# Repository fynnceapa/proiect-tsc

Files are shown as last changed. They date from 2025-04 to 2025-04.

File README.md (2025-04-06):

# OpenBook Project for Systems Testing
# Stan Andrei Razvan (Group 333CA)  

## Block Diagram
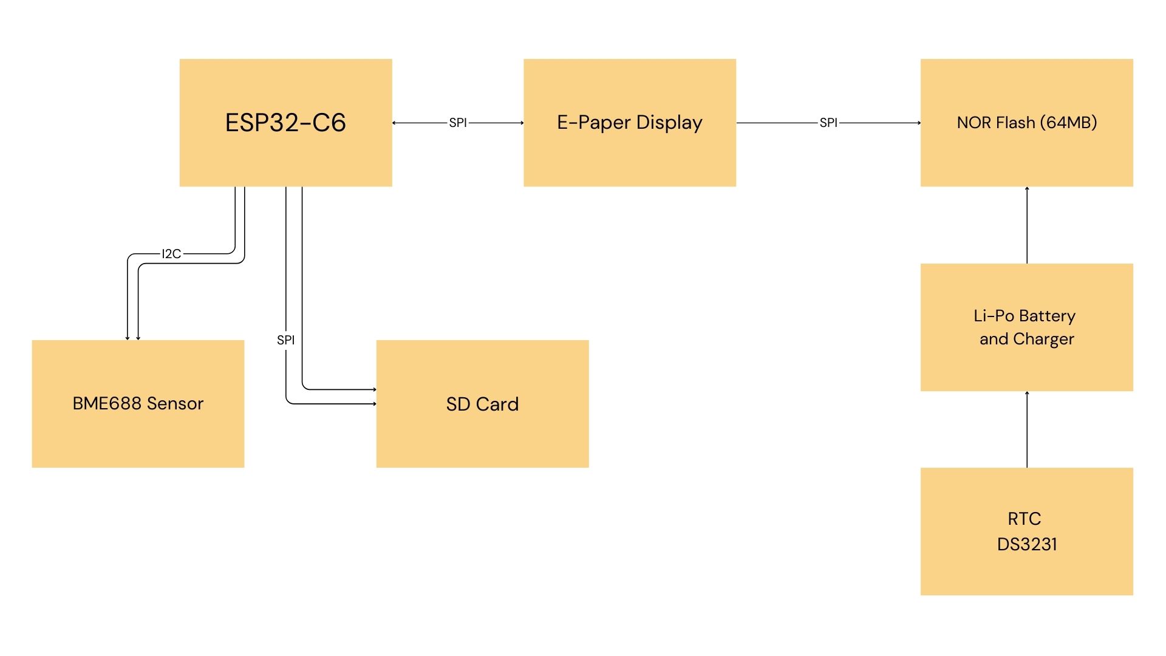
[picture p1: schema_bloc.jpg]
Block Diagram System Block Diagram
  

## Steps took
I followed the schematic and board layout provided by the teacher as closely as I could in Fusion 360.

The problems started when I began placing the components on the board. Most of the difficulties were related to identifying which discrete components to place and where, in order to make the routing process easier and more efficient.

I decided to route the board using two layers—top and bottom—and used vias where necessary. My lack of routing skills comes from the fact that i did not play around in Fusion that much...

## Core Components  

### 1. ESP32-C6 Microcontroller (Main Board)  
- **Processor:** 32-bit RISC-V @ 160MHz  
- **Wireless:** Wi-Fi 6 (802.11ax) + Bluetooth 5  
- **Memory:**  
  - 320KB RAM  
  - 512KB internal Flash (expandable via external NOR Flash)  
- **I/O:** 30+ GPIOs supporting SPI, I2C, UART, USB 2.0  

### 2. Peripheral Modules  

| Module | Interface | Speed | Key ESP32-C6 Pins |  
|---|---|---|---|
| E-Paper Display | SPI | 10-40 MHz | `EPD_CS`, MOSI, SCK |  
| BME688 Sensor | I2C | 400 kHz | SCL, SDA |  
| DS3231 RTC | I2C | 100 kHz | SCL, SDA |  
| NOR Flash | SPI/QSPI  | 133 MHz | `FLASH_CS`, MOSI, SCK |  
| SD Card | SPI | 25 MHz | `SS_SD`, MOSI, SCK |  

## Module Specifications  

### A. E-Paper Display  
- **Type:** SPI-based (e.g., Waveshare)  
- **Key Pins:**  
  - `EPD_RST`: Hardware reset  
  - `EPD_DC`: Data/command control  
  - `EPD_BUSY`: Status monitoring  
- **Power:**  
  - 150mA (active refresh)  
  - 0mA (static display)  

### B. BME688 Environmental Sensor  
- **Metrics:** Temperature, humidity, pressure, VOC  
- **Accuracy:** ±0.5°C, ±3% RH  
- **Power:** 3.6mA (active), 2.1µA (sleep)  

### C. DS3231 Real-Time Clock  
- **Precision:** ±2ppm (±1min/year)  
- **Features:** Battery backup (`VBAT`), alarm interrupts (`INT_RTC`)  

### D. Storage Systems  
- **NOR Flash (W25Q512JVEIQ):**  
  - 64MB capacity  
  - QSPI @ 133MHz  
- **SD Card:**  
  - SPI interface @ 25MHz  

### E. Power Management  
- **Charger:** MCP73831 (Li-Po, 5V USB → 4.2V)  
- **LDO Regulator:** XC6220A331MR-G (3.3V logic)  
- **Battery Monitor:** MAX17048G+T10 (I2C)  

## Power Analysis  
| Mode | Current Draw | Runtime* |  
|---|---|---|
| Active Operation | ~230mA | ~4h |  
| Deep Sleep | ~6µA | ~2 years |  

*With 1000mAh Li-Po battery  

## Low-Power Design Strategies  
- Deep-sleep mode with RTC wake-up  
- Selective peripheral power control  
- SPI/I2C bus deactivation when idle  

## Pinout Summary  

| Function | Key Pins | Purpose |  
|---|---|---|
| **E-Paper** | `EPD_CS`, `EPD_DC` | Display control |  
| **NOR Flash** | `FLASH_CS` | External memory access |  
| **RTC** | `INT_RTC`, `32KHZ` | Timekeeping & alarms |  
| **BME688** | `SCL`, `SDA` | Environmental sensing |  
| **Power** | `VBAT`, `3V3` | Battery & regulated power |

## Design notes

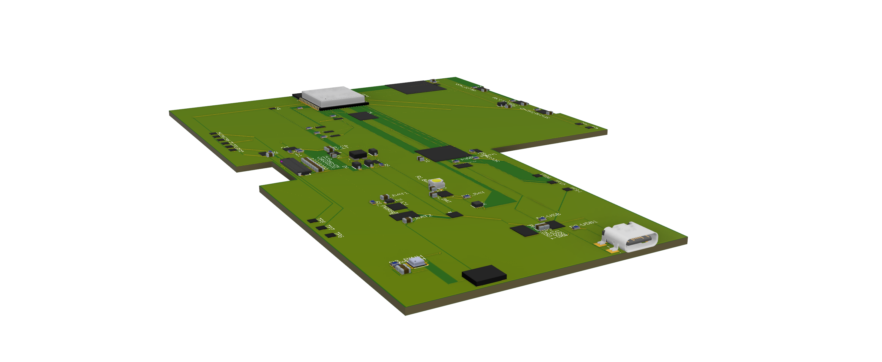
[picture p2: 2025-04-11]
Images/proiect2.png

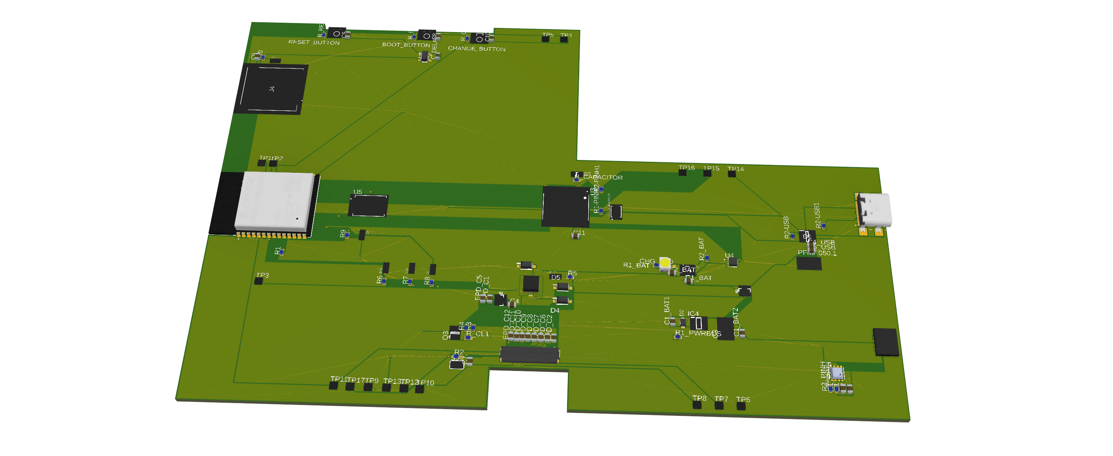
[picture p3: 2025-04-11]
Images/proiect.png

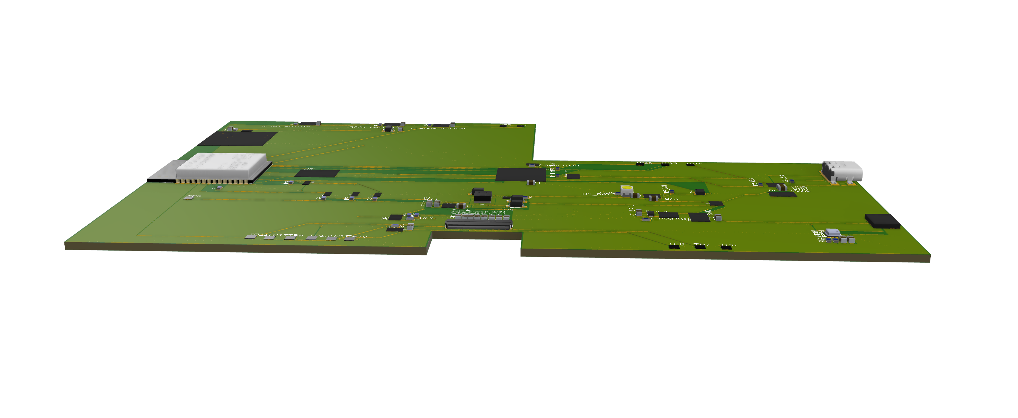
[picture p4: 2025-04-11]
Images/proiect3.png

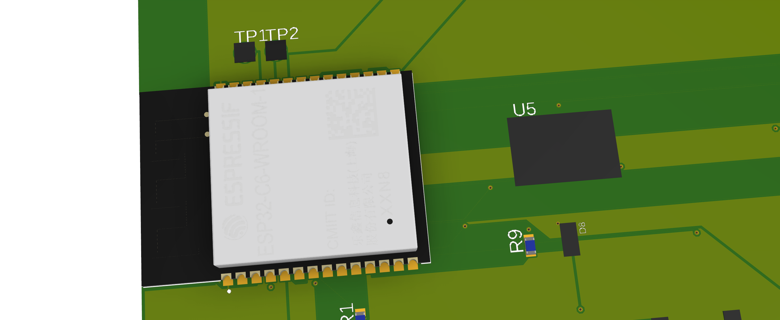
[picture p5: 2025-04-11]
Images/proiect4.png

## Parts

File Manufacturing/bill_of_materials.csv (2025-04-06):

Part | Value | Device | Package | Description | ARROW_PART_NUMBER | ARROW_PRICE-STOCK | AVAILABILITY | CENTROID_NOT_SPECIFIED | CHECK_PRICES | COPYRIGHT | DATASHEET | DESCRIPTION | DIGIKEY_DESCRIPTION | DIGIKEY_PART_NUMBER | HEIGHT | LEAD_FREE | MANUFACTURER_NAME | MANUFACTURER_PART_NUMBER | MF | MFR_NAME | MOUSER_PART_NUMBER | MOUSER_PRICE-STOCK | MOUSER_TESTING_PART_NUMBER | MOUSER_TESTING_PRICE-STOCK | MP | MPN | PACKAGE | POPULARITY | PREFIX | PRICE | PROD_ID | PURCHASE-URL | ROHS | SNAPEDA_LINK | SPICEMODEL | SPICEPREFIX | TEMPERATURE_RANGE_HIGH | TEMPERATURE_RANGE_LOW | TP_SIGNAL_NAME | VALUE
BOOT_BUTTON | BUTTON_CUSYOMV1 | BUTTON_CUSYOMV1 | MYBUTTON
C1 | 100nF | ESP32_WROVER_EAGLE-LTSPICE_CC0402 | ESP32_WROVER_EAGLE-LTSPICE_C0402 | CAPACITOR, European symbol |  |  |  |  |  |  |  |  |  |  |  |  |  |  |  |  |  |  |  |  |  |  |  |  |  |  |  |  |  |  | NONE | C
C1_BAT | 4.7uF | EAGLE-LTSPICE_CC0402 | EAGLE-LTSPICE_C0402 | CAPACITOR, European symbol |  |  |  |  |  |  |  |  |  |  |  |  |  |  |  |  |  |  |  |  |  |  |  |  |  |  |  |  |  |  | NONE | C
C1_BAT1 | 4.7uF | EAGLE-LTSPICE_CC0402 | EAGLE-LTSPICE_C0402 | CAPACITOR, European symbol |  |  |  |  |  |  |  |  |  |  |  |  |  |  |  |  |  |  |  |  |  |  |  |  |  |  |  |  |  |  | NONE | C
C1_BAT2 | 4.7uF | EAGLE-LTSPICE_CC0402 | EAGLE-LTSPICE_C0402 | CAPACITOR, European symbol |  |  |  |  |  |  |  |  |  |  |  |  |  |  |  |  |  |  |  |  |  |  |  |  |  |  |  |  |  |  | NONE | C
C2 | 100nF | ESP32_WROVER_EAGLE-LTSPICE_CC0402 | ESP32_WROVER_EAGLE-LTSPICE_C0402 | CAPACITOR, European symbol |  |  |  |  |  |  |  |  |  |  |  |  |  |  |  |  |  |  |  |  |  |  |  |  |  |  |  |  |  |  | NONE | C
C2_BAT | 4.7uF | EAGLE-LTSPICE_CC0402 | EAGLE-LTSPICE_C0402 | CAPACITOR, European symbol |  |  |  |  |  |  |  |  |  |  |  |  |  |  |  |  |  |  |  |  |  |  |  |  |  |  |  |  |  |  | NONE | C
C3 | 100uF TANT | RCL_CPOL-EUCT3528 | RCL_CT3528 | POLARIZED CAPACITOR, European symbol |  |  |  |  |  |  |  |  |  |  |  |  |  |  |  |  |  |  |  |  |  |  |  | 0 |  |  |  |  |  |  |  | C
C4 | 4.7uF/25V | EAGLE-LTSPICE_CC0402 | EAGLE-LTSPICE_C0402 | CAPACITOR, European symbol |  |  |  |  |  |  |  |  |  |  |  |  |  |  |  |  |  |  |  |  |  |  |  |  |  |  |  |  |  |  | NONE | C
C4_USB | 100nF | EAGLE-LTSPICE_CC0402 | EAGLE-LTSPICE_C0402 | CAPACITOR, European symbol |  |  |  |  |  |  |  |  |  |  |  |  |  |  |  |  |  |  |  |  |  |  |  |  |  |  |  |  |  |  | NONE | C
C5 | 1uF | EAGLE-LTSPICE_CC0402 | EAGLE-LTSPICE_C0402 | CAPACITOR, European symbol |  |  |  |  |  |  |  |  |  |  |  |  |  |  |  |  |  |  |  |  |  |  |  |  |  |  |  |  |  |  | NONE | C
C5_USB | 4.7uF | EAGLE-LTSPICE_CC0402 | EAGLE-LTSPICE_C0402 | CAPACITOR, European symbol |  |  |  |  |  |  |  |  |  |  |  |  |  |  |  |  |  |  |  |  |  |  |  |  |  |  |  |  |  |  | NONE | C
C7 | 10uF | EAGLE-LTSPICE_CC0402 | EAGLE-LTSPICE_C0402 | CAPACITOR, European symbol |  |  |  |  |  |  |  |  |  |  |  |  |  |  |  |  |  |  |  |  |  |  |  |  |  |  |  |  |  |  | NONE | C
C8 | 100nF | EAGLE-LTSPICE_CC0402 | EAGLE-LTSPICE_C0402 | CAPACITOR, European symbol |  |  |  |  |  |  |  |  |  |  |  |  |  |  |  |  |  |  |  |  |  |  |  |  |  |  |  |  |  |  | NONE | C
C9 |  | EAGLE-LTSPICE_CC0402 | EAGLE-LTSPICE_C0402 | CAPACITOR, European symbol |  |  |  |  |  |  |  |  |  |  |  |  |  |  |  |  |  |  |  |  |  |  |  |  |  |  |  |  |  |  | NONE | C
C10 | 100nF | EAGLE-LTSPICE_CC0402 | EAGLE-LTSPICE_C0402 | CAPACITOR, European symbol |  |  |  |  |  |  |  |  |  |  |  |  |  |  |  |  |  |  |  |  |  |  |  |  |  |  |  |  |  |  | NONE | C
C10_SUPERCAP | CPH3225A | CPH3225A | CAPCP3225X100N | Cap 0.011F 3.3V 1210 Flat Check availability |  |  | Not in stock |  | https://www.snapeda.com/parts/CPH3225A/Seiko+Instruments/view-part/?ref=eda |  |  | 11 mF (EDLC) Supercapacitor 3.3 V 1210 (3225 Metric) - - |  |  |  |  |  |  | Seiko Instruments |  |  |  |  |  | CPH3225A |  | 1210 Seiko |  |  | None |  | https://www.snapeda.com/api/url_track_click_mouser/?unipart_id=562593&manufacturer=Seiko Instruments&part_name=CPH3225A&search_term=None |  | https://www.snapeda.com/parts/CPH3225A/Seiko+Instruments/view-part/?ref=snap
C11 | 100nF | EAGLE-LTSPICE_CC0402 | EAGLE-LTSPICE_C0402 | CAPACITOR, European symbol |  |  |  |  |  |  |  |  |  |  |  |  |  |  |  |  |  |  |  |  |  |  |  |  |  |  |  |  |  |  | NONE | C
CHANGE_BUTTON | BUTTON_CUSYOMV1 | BUTTON_CUSYOMV1 | MYBUTTON
CHG_LED |  | ADAFRUIT_LEDCHIP-LED0603 | ADAFRUIT_CHIP-LED0603 | LED
C_DELAY | 100nF | EAGLE-LTSPICE_CC0402 | EAGLE-LTSPICE_C0402 | CAPACITOR, European symbol |  |  |  |  |  |  |  |  |  |  |  |  |  |  |  |  |  |  |  |  |  |  |  |  |  |  |  |  |  |  | NONE | C
D1 | USBLC6-2SC6Y | USBLC6-2SC6Y | SOT95P280X145-6N | Low Cap. ESD Protection Auto SOT-23-6 STMicroelectronics USBLC6-2SC6Y, Dual Uni-Directional TVS Diode Array, 6-Pin SOT-23 |  |  | In Stock |  | https://www.snapeda.com/parts/USBLC6-2SC6Y/STMicroelectronics/view-part/?ref=eda |  |  | 17V Clamp 5A (8/20µs) Ipp Tvs Diode Surface Mount SOT-23-6 |  |  |  |  |  |  | STMicroelectronics |  |  |  |  |  | USBLC6-2SC6Y |  | SOT-23-6 STMicroelectronics |  |  | None |  |  |  | https://www.snapeda.com/parts/USBLC6-2SC6Y/STMicroelectronics/view-part/?ref=snap
D2 | ESP32_WROVER_AVX---SD0805S020S1R0_AVX_SD0805S020S1R0_0_0AVX_SD0805S020S1R0_0_0 | ESP32_WROVER_AVX---SD0805S020S1R0_AVX_SD0805S020S1R0_0_0AVX_SD0805S020S1R0_0_0 | ESP32_WROVER_AVX---SD0805S020S1R0_AVX_SD0805S020S1R0_0 | Schottky Barrier Rectifier Diode |  |  |  | No |  |  | http://datasheets.avx.com/schottky.pdf |  | DIODE SCHOTTKY 20V 1A 0805 | 478-7800-1-ND |  | yes |  |  | AVX |  | 581-SD0805S020S1R0 |  |  |  |  |  | 0805 (2012 metric) |  | D |  |  |  | yes |  |  |  | +125°C | -55°C
D3 | MBR0530 | MBR0530 | SOD3716X135N | ON SEMICONDUCTOR - MBR0530 - DIODE, SCHOTTKY, 0.5A, 30V, SOD-123 |  |  | In Stock |  | https://www.snapeda.com/parts/MBR0530/Onsemi/view-part/?ref=eda |  |  | Diode Schottky 30 V 500mA Surface Mount SOD-123 |  |  |  |  |  |  | ON Semiconductor |  |  |  |  |  | MBR0530 |  | SOD-123-2 ON Semiconductor |  |  | None |  | https://www.snapeda.com/api/url_track_click_mouser/?unipart_id=179458&manufacturer=ON Semiconductor&part_name=MBR0530&search_term=None |  | https://www.snapeda.com/parts/MBR0530/Onsemi/view-part/?ref=snap
D4 | MBR0530 | MBR0530 | SOD3716X135N | ON SEMICONDUCTOR - MBR0530 - DIODE, SCHOTTKY, 0.5A, 30V, SOD-123 |  |  | In Stock |  | https://www.snapeda.com/parts/MBR0530/Onsemi/view-part/?ref=eda |  |  | Diode Schottky 30 V 500mA Surface Mount SOD-123 |  |  |  |  |  |  | ON Semiconductor |  |  |  |  |  | MBR0530 |  | SOD-123-2 ON Semiconductor |  |  | None |  | https://www.snapeda.com/api/url_track_click_mouser/?unipart_id=179458&manufacturer=ON Semiconductor&part_name=MBR0530&search_term=None |  | https://www.snapeda.com/parts/MBR0530/Onsemi/view-part/?ref=snap
D5 | MBR0530 | MBR0530 | SOD3716X135N | ON SEMICONDUCTOR - MBR0530 - DIODE, SCHOTTKY, 0.5A, 30V, SOD-123 |  |  | In Stock |  | https://www.snapeda.com/parts/MBR0530/Onsemi/view-part/?ref=eda |  |  | Diode Schottky 30 V 500mA Surface Mount SOD-123 |  |  |  |  |  |  | ON Semiconductor |  |  |  |  |  | MBR0530 |  | SOD-123-2 ON Semiconductor |  |  | None |  | https://www.snapeda.com/api/url_track_click_mouser/?unipart_id=179458&manufacturer=ON Semiconductor&part_name=MBR0530&search_term=None |  | https://www.snapeda.com/parts/MBR0530/Onsemi/view-part/?ref=snap
D6 | PGB1010603MR | PGB1010603MR | DIOC1608X36N | Check availability |  |  | In Stock |  | https://www.snapeda.com/parts/PGB1010603MR/Littelfuse/view-part/?ref=eda |  |  | 150V (Typ) Clamp - Ipp Tvs Diode Surface Mount 0603 (1608 Metric) |  |  |  |  |  |  | Littelfuse Inc. |  |  |  |  |  | PGB1010603MR |  | 0603 Littelfuse Inc. |  |  | None |  | https://www.snapeda.com/api/url_track_click_mouser/?unipart_id=5659453&manufacturer=Littelfuse Inc.&part_name=PGB1010603MR&search_term=None |  | https://www.snapeda.com/parts/PGB1010603MR/Littelfuse/view-part/?ref=snap
D7 | ESP32_WROVER_AVX---SD0805S020S1R0_AVX_SD0805S020S1R0_0_0AVX_SD0805S020S1R0_0_0 | ESP32_WROVER_AVX---SD0805S020S1R0_AVX_SD0805S020S1R0_0_0AVX_SD0805S020S1R0_0_0 | ESP32_WROVER_AVX---SD0805S020S1R0_AVX_SD0805S020S1R0_0 | Schottky Barrier Rectifier Diode |  |  |  | No |  |  | http://datasheets.avx.com/schottky.pdf |  | DIODE SCHOTTKY 20V 1A 0805 | 478-7800-1-ND |  | yes |  |  | AVX |  | 581-SD0805S020S1R0 |  |  |  |  |  | 0805 (2012 metric) |  | D |  |  |  | yes |  |  |  | +125°C | -55°C
D8 | PGB1010603MR | PGB1010603MR | DIOC1608X36N | Check availability |  |  | In Stock |  | https://www.snapeda.com/parts/PGB1010603MR/Littelfuse/view-part/?ref=eda |  |  | 150V (Typ) Clamp - Ipp Tvs Diode Surface Mount 0603 (1608 Metric) |  |  |  |  |  |  | Littelfuse Inc. |  |  |  |  |  | PGB1010603MR |  | 0603 Littelfuse Inc. |  |  | None |  | https://www.snapeda.com/api/url_track_click_mouser/?unipart_id=5659453&manufacturer=Littelfuse Inc.&part_name=PGB1010603MR&search_term=None |  | https://www.snapeda.com/parts/PGB1010603MR/Littelfuse/view-part/?ref=snap
D9 | PGB1010603MR | PGB1010603MR | DIOC1608X36N | Check availability |  |  | In Stock |  | https://www.snapeda.com/parts/PGB1010603MR/Littelfuse/view-part/?ref=eda |  |  | 150V (Typ) Clamp - Ipp Tvs Diode Surface Mount 0603 (1608 Metric) |  |  |  |  |  |  | Littelfuse Inc. |  |  |  |  |  | PGB1010603MR |  | 0603 Littelfuse Inc. |  |  | None |  | https://www.snapeda.com/api/url_track_click_mouser/?unipart_id=5659453&manufacturer=Littelfuse Inc.&part_name=PGB1010603MR&search_term=None |  | https://www.snapeda.com/parts/PGB1010603MR/Littelfuse/view-part/?ref=snap
D10 | PGB1010603MR | PGB1010603MR | DIOC1608X36N | Check availability |  |  | In Stock |  | https://www.snapeda.com/parts/PGB1010603MR/Littelfuse/view-part/?ref=eda |  |  | 150V (Typ) Clamp - Ipp Tvs Diode Surface Mount 0603 (1608 Metric) |  |  |  |  |  |  | Littelfuse Inc. |  |  |  |  |  | PGB1010603MR |  | 0603 Littelfuse Inc. |  |  | None |  | https://www.snapeda.com/api/url_track_click_mouser/?unipart_id=5659453&manufacturer=Littelfuse Inc.&part_name=PGB1010603MR&search_term=None |  | https://www.snapeda.com/parts/PGB1010603MR/Littelfuse/view-part/?ref=snap
D11 | PGB1010603MR | PGB1010603MR | DIOC1608X36N | Check availability |  |  | In Stock |  | https://www.snapeda.com/parts/PGB1010603MR/Littelfuse/view-part/?ref=eda |  |  | 150V (Typ) Clamp - Ipp Tvs Diode Surface Mount 0603 (1608 Metric) |  |  |  |  |  |  | Littelfuse Inc. |  |  |  |  |  | PGB1010603MR |  | 0603 Littelfuse Inc. |  |  | None |  | https://www.snapeda.com/api/url_track_click_mouser/?unipart_id=5659453&manufacturer=Littelfuse Inc.&part_name=PGB1010603MR&search_term=None |  | https://www.snapeda.com/parts/PGB1010603MR/Littelfuse/view-part/?ref=snap
D12 | PGB1010603MR | PGB1010603MR | DIOC1608X36N | Check availability |  |  | In Stock |  | https://www.snapeda.com/parts/PGB1010603MR/Littelfuse/view-part/?ref=eda |  |  | 150V (Typ) Clamp - Ipp Tvs Diode Surface Mount 0603 (1608 Metric) |  |  |  |  |  |  | Littelfuse Inc. |  |  |  |  |  | PGB1010603MR |  | 0603 Littelfuse Inc. |  |  | None |  | https://www.snapeda.com/api/url_track_click_mouser/?unipart_id=5659453&manufacturer=Littelfuse Inc.&part_name=PGB1010603MR&search_term=None |  | https://www.snapeda.com/parts/PGB1010603MR/Littelfuse/view-part/?ref=snap
EPD_C1 | 1uF/50V | EAGLE-LTSPICE_CC0402 | EAGLE-LTSPICE_C0402 | CAPACITOR, European symbol |  |  |  |  |  |  |  |  |  |  |  |  |  |  |  |  |  |  |  |  |  |  |  |  |  |  |  |  |  |  | NONE | C
EPD_C2 | 1uF/50V | EAGLE-LTSPICE_CC0402 | EAGLE-LTSPICE_C0402 | CAPACITOR, European symbol |  |  |  |  |  |  |  |  |  |  |  |  |  |  |  |  |  |  |  |  |  |  |  |  |  |  |  |  |  |  | NONE | C
EPD_C5 | 0.1uF/50V | EAGLE-LTSPICE_CC0402 | EAGLE-LTSPICE_C0402 | CAPACITOR, European symbol |  |  |  |  |  |  |  |  |  |  |  |  |  |  |  |  |  |  |  |  |  |  |  |  |  |  |  |  |  |  | NONE | C
EPD_C6 | 1uF/50V | EAGLE-LTSPICE_CC0402 | EAGLE-LTSPICE_C0402 | CAPACITOR, European symbol |  |  |  |  |  |  |  |  |  |  |  |  |  |  |  |  |  |  |  |  |  |  |  |  |  |  |  |  |  |  | NONE | C
EPD_C7 | 1uF/50V | EAGLE-LTSPICE_CC0402 | EAGLE-LTSPICE_C0402 | CAPACITOR, European symbol |  |  |  |  |  |  |  |  |  |  |  |  |  |  |  |  |  |  |  |  |  |  |  |  |  |  |  |  |  |  | NONE | C
EPD_C8 | 1uF/50V | EAGLE-LTSPICE_CC0402 | EAGLE-LTSPICE_C0402 | CAPACITOR, European symbol |  |  |  |  |  |  |  |  |  |  |  |  |  |  |  |  |  |  |  |  |  |  |  |  |  |  |  |  |  |  | NONE | C
EPD_C9 | 1uF/50V | EAGLE-LTSPICE_CC0402 | EAGLE-LTSPICE_C0402 | CAPACITOR, European symbol |  |  |  |  |  |  |  |  |  |  |  |  |  |  |  |  |  |  |  |  |  |  |  |  |  |  |  |  |  |  | NONE | C
EPD_C10 | 1uF/50V | EAGLE-LTSPICE_CC0402 | EAGLE-LTSPICE_C0402 | CAPACITOR, European symbol |  |  |  |  |  |  |  |  |  |  |  |  |  |  |  |  |  |  |  |  |  |  |  |  |  |  |  |  |  |  | NONE | C
EPD_C11 | 1uF/50V | EAGLE-LTSPICE_CC0402 | EAGLE-LTSPICE_C0402 | CAPACITOR, European symbol |  |  |  |  |  |  |  |  |  |  |  |  |  |  |  |  |  |  |  |  |  |  |  |  |  |  |  |  |  |  | NONE | C
EPD_C12 | 1uF/50V | EAGLE-LTSPICE_CC0402 | EAGLE-LTSPICE_C0402 | CAPACITOR, European symbol |  |  |  |  |  |  |  |  |  |  |  |  |  |  |  |  |  |  |  |  |  |  |  |  |  |  |  |  |  |  | NONE | C
IC1 | BD5229G-TR | BD5229G-TR | SOT95P280X125-5N | Voltage Detector with Adjustable Delay Time: CMOS processes are utilized to develop high precision, low current consumption CMOS reset ICs that allow arbitrary setting of the delay time. The extensive lineup includes both Nch Open Drain and CMOS output types in a wide range of detection voltages (from 2.3V to 6.0V, in 0.1V steps), enabling selection of the ideal solution based on customer requirements. In addition, the entire series is of course both lead-free and RoHS-compliant. |  |  |  |  |  |  |  | Voltage Detector with Adjustable Delay Time: CMOS processes are utilized to develop high precision | low current consumption CMOS reset ICs that allow arbitrary setting of the delay time. The extensive lineup includes both Nch Open Drain and CMOS output types in a wide range of detection voltages (from 2.3V to 6.0V | in 0.1V steps) | enabling selection of the ideal solution based on customer requirements. In addition | the entire series is of course both lead-free and RoHS-compliant. |  |  | 1.25mm |  | ROHM Semiconductor | BD5229G-TR |  |  | 755-BD5229G-TR | https://www.mouser.co.uk/ProductDetail/ROHM-Semiconductor/BD5229G-TR?qs=4kLU8WoGk0vvnhrrYwdszw%3D%3D
IC4 | XC6220A331MR-G | XC6220A331MR-G | SOT95P280X120-5N | LDO Voltage Regulators |  |  |  |  |  |  |  | LDO Voltage Regulators |  |  | 1.2mm |  | Torex | XC6220A331MR-G |  |  | 865-XC6220A331MR-G | https://www.mouser.co.uk/ProductDetail/Torex-Semiconductor/XC6220A331MR-G?qs=AsjdqWjXhJ8ZSWznL1J0gg%3D%3D
J1 | FH34SRJ-24S-0.5SH_99_ | FH34SRJ-24S-0.5SH_99_ | FH34SRJ24S05SH99 | (0.50mm) Surface Mount, Right Angle |  |  |  |  |  |  |  | 24 Position FFC | FPC Connector Contacts | (0.50mm) Surface Mount | Right Angle |  |  | 1.1mm |  | Hirose | FH34SRJ-24S-0.5SH(99) |  |  | 798-FH34SRJ24S05SH99 | https://www.mouser.co.uk/ProductDetail/Hirose-Connector/FH34SRJ-24S-0.5SH99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
J2 | SAMACSYS_PARTS_USB4110-GF-A | SAMACSYS_PARTS_USB4110-GF-A | SAMACSYS_PARTS_USB4110GFA | CONN USB 2.0 TYPE-C R/A SMT |  |  |  |  |  |  |  | CONN USB 2.0 TYPE-C R/A SMT |  |  | 3.26mm |  | GCT (GLOBAL CONNECTOR TECHNOLOGY) | USB4110-GF-A |  |  | 640-USB4110-GF-A | https://www.mouser.co.uk/ProductDetail/GCT/USB4110-GF-A?qs=KUoIvG%2F9IlYiZvIXQjyJeA%3D%3D
J3 | QWIIC_RIGHT_ANGLE | QWIIC_CONNECTORJS-1MM | JST04_1MM_RA | SparkFun I2C Standard Qwiic Connector |  |  |  |  |  |  |  |  |  |  |  |  |  |  |  |  |  |  |  |  |  |  |  |  |  |  | CONN-13694 |  |  |  |  |  |  |  |  | QWIIC_RIGHT_ANGLE
J4 | 112A-TAAR-R03_ATTEND | 112A-TAAR-R03_ATTEND | 112ATAARR03ATTEND | Micro SD Card Socket, Push-Push Type, Top Mount, SMT, H=1.83mm, 10u |  |  |  |  |  |  |  | Micro SD Card Socket | Push-Push Type | Top Mount | SMT | H=1.83mm | 10u |  |  | 1.9mm |  | ATTEND | 112A-TAAR-R03 ATTEND
L1 | 68uH | 744043680IND_4828-WE-TPC_WRE | IND_4828-WE-TPC_WRE |  |  |  |  |  |  | Copyright (C) 2024 Ultra Librarian. All rights reserved. |  |  |  |  |  |  |  | 744043680 |  | Wurth Electronics
PFMF.050.1 | ESP32C6_VARISTORCN1812 | ESP32C6_VARISTORCN1812 | ESP32C6_VARISTOR_CT/CN1812 | VARISTOR |  |  |  |  |  |  |  |  |  |  |  |  |  |  |  |  |  |  |  |  |  |  |  | 0
Q1 | 20V/4.2A/52mΩ/1.4W | ESP32_WROVER_SPARKFUN-DISCRETESEMI_MOSFET_PCH-DMG2305UX-7 | ESP32_WROVER_SPARKFUN-DISCRETESEMI_SOT23-3 | P-channel MOSFETs |  |  |  |  |  |  |  |  |  |  |  |  |  |  |  |  |  |  |  |  |  |  |  |  |  |  | TRAN-14388 |  |  |  |  |  |  |  |  | 20V/4.2A/52mΩ/1.4W
Q2 | 20V/4.2A/52mΩ/1.4W | ESP32_WROVER_SPARKFUN-DISCRETESEMI_MOSFET_PCH-DMG2305UX-7 | ESP32_WROVER_SPARKFUN-DISCRETESEMI_SOT23-3 | P-channel MOSFETs |  |  |  |  |  |  |  |  |  |  |  |  |  |  |  |  |  |  |  |  |  |  |  |  |  |  | TRAN-14388 |  |  |  |  |  |  |  |  | 20V/4.2A/52mΩ/1.4W
Q3 | SI1308EDL-T1-GE3 | SI1308EDL-T1-GE3 | SOT65P210X110-3N | MOSFET N-Ch 30V 1.5A TrenchFET SC70 Vishay Si1308EDL-T1-GE3 N-channel MOSFET Transistor, 1.5 A, 30 V, 3-Pin SC-70 |  |  | In Stock |  | https://www.snapeda.com/parts/SI1308EDL-T1-GE3/Vishay+Siliconix/view-part/?ref=eda |  |  | Si1308EDL-T1-GE3 N-channel MOSFET Transistor | 1.5 A | 30 V | 3-Pin SC-70 | Siliconix / Vishay SI1308EDL-T1-GE3 |  |  |  |  |  |  | Vishay Siliconix |  |  |  |  |  | SI1308EDL-T1-GE3 |  | SOT-323 Vishay Semiconductor |  |  | None |  | https://www.snapeda.com/api/url_track_click_mouser/?unipart_id=274603&manufacturer=Vishay Siliconix&part_name=SI1308EDL-T1-GE3&search_term=None |  | https://www.snapeda.com/parts/SI1308EDL-T1-GE3/Vishay+Siliconix/view-part/?ref=snap
R1 | 10K | ESP32_WROVER_EAGLE-LTSPICE_RR0402 | ESP32_WROVER_EAGLE-LTSPICE_R0402 | RESISTOR, European symbol |  |  |  |  |  |  |  |  |  |  |  |  |  |  |  |  |  |  |  |  |  |  |  |  |  |  |  |  |  |  | NONE | R
R1-PINH1 | 10k | ESP32_WROVER_EAGLE-LTSPICE_RR0402 | ESP32_WROVER_EAGLE-LTSPICE_R0402 | RESISTOR, European symbol |  |  |  |  |  |  |  |  |  |  |  |  |  |  |  |  |  |  |  |  |  |  |  |  |  |  |  |  |  |  | NONE | R
R1_BAT | 200 | ESP32_WROVER_EAGLE-LTSPICE_RR0402 | ESP32_WROVER_EAGLE-LTSPICE_R0402 | RESISTOR, European symbol |  |  |  |  |  |  |  |  |  |  |  |  |  |  |  |  |  |  |  |  |  |  |  |  |  |  |  |  |  |  | NONE | R
R1_PINH |  | ESP32_WROVER_EAGLE-LTSPICE_RR0402 | ESP32_WROVER_EAGLE-LTSPICE_R0402 | RESISTOR, European symbol |  |  |  |  |  |  |  |  |  |  |  |  |  |  |  |  |  |  |  |  |  |  |  |  |  |  |  |  |  |  | NONE | R
R1_PWRBUS | 100k | ESP32_WROVER_EAGLE-LTSPICE_RR0402 | ESP32_WROVER_EAGLE-LTSPICE_R0402 | RESISTOR, European symbol |  |  |  |  |  |  |  |  |  |  |  |  |  |  |  |  |  |  |  |  |  |  |  |  |  |  |  |  |  |  | NONE | R
R2 | 2.2 | ESP32_WROVER_EAGLE-LTSPICE_RR0402 | ESP32_WROVER_EAGLE-LTSPICE_R0402 | RESISTOR, European symbol |  |  |  |  |  |  |  |  |  |  |  |  |  |  |  |  |  |  |  |  |  |  |  |  |  |  |  |  |  |  | NONE | R
R2-PINH1 | 10k | ESP32_WROVER_EAGLE-LTSPICE_RR0402 | ESP32_WROVER_EAGLE-LTSPICE_R0402 | RESISTOR, European symbol |  |  |  |  |  |  |  |  |  |  |  |  |  |  |  |  |  |  |  |  |  |  |  |  |  |  |  |  |  |  | NONE | R
R2-USB | 5k1 | ESP32_WROVER_EAGLE-LTSPICE_RR0402 | ESP32_WROVER_EAGLE-LTSPICE_R0402 | RESISTOR, European symbol |  |  |  |  |  |  |  |  |  |  |  |  |  |  |  |  |  |  |  |  |  |  |  |  |  |  |  |  |  |  | NONE | R
R2-USB1 | 5k1 | ESP32_WROVER_EAGLE-LTSPICE_RR0402 | ESP32_WROVER_EAGLE-LTSPICE_R0402 | RESISTOR, European symbol |  |  |  |  |  |  |  |  |  |  |  |  |  |  |  |  |  |  |  |  |  |  |  |  |  |  |  |  |  |  | NONE | R
R2_BAT | 2k | ESP32_WROVER_EAGLE-LTSPICE_RR0402 | ESP32_WROVER_EAGLE-LTSPICE_R0402 | RESISTOR, European symbol |  |  |  |  |  |  |  |  |  |  |  |  |  |  |  |  |  |  |  |  |  |  |  |  |  |  |  |  |  |  | NONE | R
R2_PINH |  | ESP32_WROVER_EAGLE-LTSPICE_RR0402 | ESP32_WROVER_EAGLE-LTSPICE_R0402 | RESISTOR, European symbol |  |  |  |  |  |  |  |  |  |  |  |  |  |  |  |  |  |  |  |  |  |  |  |  |  |  |  |  |  |  | NONE | R
R3 | 0.47 | ESP32_WROVER_EAGLE-LTSPICE_RR0402 | ESP32_WROVER_EAGLE-LTSPICE_R0402 | RESISTOR, European symbol |  |  |  |  |  |  |  |  |  |  |  |  |  |  |  |  |  |  |  |  |  |  |  |  |  |  |  |  |  |  | NONE | R
R4 | 10K | ESP32_WROVER_EAGLE-LTSPICE_RR0402 | ESP32_WROVER_EAGLE-LTSPICE_R0402 | RESISTOR, European symbol |  |  |  |  |  |  |  |  |  |  |  |  |  |  |  |  |  |  |  |  |  |  |  |  |  |  |  |  |  |  | NONE | R
R5 | 10k | ESP32_WROVER_EAGLE-LTSPICE_RR0402 | ESP32_WROVER_EAGLE-LTSPICE_R0402 | RESISTOR, European symbol |  |  |  |  |  |  |  |  |  |  |  |  |  |  |  |  |  |  |  |  |  |  |  |  |  |  |  |  |  |  | NONE | R
R6 | 10k | ESP32_WROVER_EAGLE-LTSPICE_RR0402 | ESP32_WROVER_EAGLE-LTSPICE_R0402 | RESISTOR, European symbol |  |  |  |  |  |  |  |  |  |  |  |  |  |  |  |  |  |  |  |  |  |  |  |  |  |  |  |  |  |  | NONE | R
R7 | 10k | ESP32_WROVER_EAGLE-LTSPICE_RR0402 | ESP32_WROVER_EAGLE-LTSPICE_R0402 | RESISTOR, European symbol |  |  |  |  |  |  |  |  |  |  |  |  |  |  |  |  |  |  |  |  |  |  |  |  |  |  |  |  |  |  | NONE | R
R8 | 10k | ESP32_WROVER_EAGLE-LTSPICE_RR0402 | ESP32_WROVER_EAGLE-LTSPICE_R0402 | RESISTOR, European symbol |  |  |  |  |  |  |  |  |  |  |  |  |  |  |  |  |  |  |  |  |  |  |  |  |  |  |  |  |  |  | NONE | R
R9 | 10k | ESP32_WROVER_EAGLE-LTSPICE_RR0402 | ESP32_WROVER_EAGLE-LTSPICE_R0402 | RESISTOR, European symbol |  |  |  |  |  |  |  |  |  |  |  |  |  |  |  |  |  |  |  |  |  |  |  |  |  |  |  |  |  |  | NONE | R
R10 | 10k | ESP32_WROVER_EAGLE-LTSPICE_RR0402 | ESP32_WROVER_EAGLE-LTSPICE_R0402 | RESISTOR, European symbol |  |  |  |  |  |  |  |  |  |  |  |  |  |  |  |  |  |  |  |  |  |  |  |  |  |  |  |  |  |  | NONE | R
RESET_BUTTON | BUTTON_CUSYOMV1 | BUTTON_CUSYOMV1 | MYBUTTON
R_BOOT | 10k | ESP32_WROVER_EAGLE-LTSPICE_RR0402 | ESP32_WROVER_EAGLE-LTSPICE_R0402 | RESISTOR, European symbol |  |  |  |  |  |  |  |  |  |  |  |  |  |  |  |  |  |  |  |  |  |  |  |  |  |  |  |  |  |  | NONE | R
R_CAPACITOR | 15 | ESP32_WROVER_EAGLE-LTSPICE_RR0402 | ESP32_WROVER_EAGLE-LTSPICE_R0402 | RESISTOR, European symbol |  |  |  |  |  |  |  |  |  |  |  |  |  |  |  |  |  |  |  |  |  |  |  |  |  |  |  |  |  |  | NONE | R
R_CHANGE | 10k | ESP32_WROVER_EAGLE-LTSPICE_RR0402 | ESP32_WROVER_EAGLE-LTSPICE_R0402 | RESISTOR, European symbol |  |  |  |  |  |  |  |  |  |  |  |  |  |  |  |  |  |  |  |  |  |  |  |  |  |  |  |  |  |  | NONE | R
R_CL1 | 10K | ESP32_WROVER_EAGLE-LTSPICE_RR0402 | ESP32_WROVER_EAGLE-LTSPICE_R0402 | RESISTOR, European symbol |  |  |  |  |  |  |  |  |  |  |  |  |  |  |  |  |  |  |  |  |  |  |  |  |  |  |  |  |  |  | NONE | R
R_RESET | 10k | ESP32_WROVER_EAGLE-LTSPICE_RR0402 | ESP32_WROVER_EAGLE-LTSPICE_R0402 | RESISTOR, European symbol |  |  |  |  |  |  |  |  |  |  |  |  |  |  |  |  |  |  |  |  |  |  |  |  |  |  |  |  |  |  | NONE | R
SENSOR2 | BME688 | ESP32_WROVER_BME680_BME680 | ESP32_WROVER_BME680_PSON80P300X300X100-8N | Integrated Environmental Unit |  |  | Unavailable |  |  |  |  | Integrated Environmental Unit |  |  |  |  |  |  | Bosch Sensortec |  |  |  |  |  | BME680 |  | LGA-8 Bosch Tools |  |  | None
SJ1 |  | SJ | SJ | SMD solder JUMPER |  |  |  |  |  |  |  |  |  |  |  |  |  |  |  |  |  |  |  |  |  |  |  | 3
TP1 | TPTP20R | TPTP20R | TP20R | Test pad |  |  |  |  |  |  |  |  |  |  |  |  |  |  |  |  |  |  |  |  |  |  |  | 2
TP2 | TPTP20R | TPTP20R | TP20R | Test pad |  |  |  |  |  |  |  |  |  |  |  |  |  |  |  |  |  |  |  |  |  |  |  | 2
TP3 | TPTP20R | TPTP20R | TP20R | Test pad |  |  |  |  |  |  |  |  |  |  |  |  |  |  |  |  |  |  |  |  |  |  |  | 2
TP4 | TPTP20R | TPTP20R | TP20R | Test pad |  |  |  |  |  |  |  |  |  |  |  |  |  |  |  |  |  |  |  |  |  |  |  | 2
TP5 | TPTP20R | TPTP20R | TP20R | Test pad |  |  |  |  |  |  |  |  |  |  |  |  |  |  |  |  |  |  |  |  |  |  |  | 2
TP6 | TPTP20R | TPTP20R | TP20R | Test pad |  |  |  |  |  |  |  |  |  |  |  |  |  |  |  |  |  |  |  |  |  |  |  | 2
TP7 | TPTP20R | TPTP20R | TP20R | Test pad |  |  |  |  |  |  |  |  |  |  |  |  |  |  |  |  |  |  |  |  |  |  |  | 2
TP8 | TPTP20R | TPTP20R | TP20R | Test pad |  |  |  |  |  |  |  |  |  |  |  |  |  |  |  |  |  |  |  |  |  |  |  | 2
TP9 | TPTP20R | TPTP20R | TP20R | Test pad |  |  |  |  |  |  |  |  |  |  |  |  |  |  |  |  |  |  |  |  |  |  |  | 2
TP10 | TPTP20R | TPTP20R | TP20R | Test pad |  |  |  |  |  |  |  |  |  |  |  |  |  |  |  |  |  |  |  |  |  |  |  | 2
TP11 | TPTP20R | TPTP20R | TP20R | Test pad |  |  |  |  |  |  |  |  |  |  |  |  |  |  |  |  |  |  |  |  |  |  |  | 2
TP12 | TPTP20R | TPTP20R | TP20R | Test pad |  |  |  |  |  |  |  |  |  |  |  |  |  |  |  |  |  |  |  |  |  |  |  | 2
TP13 | TPTP20R | TPTP20R | TP20R | Test pad |  |  |  |  |  |  |  |  |  |  |  |  |  |  |  |  |  |  |  |  |  |  |  | 2
TP14 | TPTP20R | TPTP20R | TP20R | Test pad |  |  |  |  |  |  |  |  |  |  |  |  |  |  |  |  |  |  |  |  |  |  |  | 2
TP15 | TPTP20R | TPTP20R | TP20R | Test pad |  |  |  |  |  |  |  |  |  |  |  |  |  |  |  |  |  |  |  |  |  |  |  | 2
TP16 | TPTP20R | TPTP20R | TP20R | Test pad |  |  |  |  |  |  |  |  |  |  |  |  |  |  |  |  |  |  |  |  |  |  |  | 2
TP17 | TPTP20R | TPTP20R | TP20R | Test pad |  |  |  |  |  |  |  |  |  |  |  |  |  |  |  |  |  |  |  |  |  |  |  | 2
U1 | ESP32_WROVER_SPARKFUN-IC-POWER_MCP73831 | ESP32_WROVER_SPARKFUN-IC-POWER_MCP73831 | ESP32_WROVER_SPARKFUN-IC-POWER_SOT23-5 | MCP73831T Li-Ion, Li-Pol Controller |  |  |  |  |  |  |  |  |  |  |  |  |  |  |  |  |  |  |  |  |  |  |  |  |  |  | IC-09995
U2 | ESP32-C6-WROOM-1-N8 | ESP32-C6-WROOM-1-N8 | XCVR_ESP32-C6-WROOM-1-N8 | Check availability |  |  | In Stock |  | https://www.snapeda.com/parts/ESP32-C6-WROOM-1-N8/Espressif+Systems/view-part/?ref=eda |  |  | Multiprotocol Modules ESP32-C6 module | Wi-Fi 6 in 2.4 GHz band | Bluetooth 5 | Zigbee 3.0 and Thread. ESP34-WROOM Compatible - ENGINEERING SAMPLE |  |  |  |  |  |  | Espressif Systems |  |  |  |  |  | ESP32-C6-WROOM-1-N8 |  | None |  |  | None |  |  |  | https://www.snapeda.com/parts/ESP32-C6-WROOM-1-N8/Espressif+Systems/view-part/?ref=snap
U3 | DS3231SN# | DS3231SN# | SOIC127P1032X265-16N | Real Time Clock Serial 16-Pin SOIC W T/R Check availability |  |  | In Stock |  | https://www.snapeda.com/parts/DS3231SN%23/Analog+Devices/view-part/?ref=eda |  |  | Extremely Accurate I²C-Integrated RTC/TCXO/Crystal |  |  |  |  |  |  | Analog Devices |  |  |  |  |  | DS3231SN# |  | SOIC-16 Maxim |  |  | None |  | https://www.snapeda.com/api/url_track_click_mouser/?unipart_id=99048&manufacturer=Analog Devices&part_name=DS3231SN#&search_term=None |  | https://www.snapeda.com/parts/DS3231SN%23/Analog+Devices/view-part/?ref=snap
U4 | MAX17048G+T10 | MAX17048G+T10 | SON50P200X200X80-9N | Check availability |  |  | In Stock |  | https://www.snapeda.com/parts/MAX17048G+T10/Analog+Devices/view-part/?ref=eda |  |  | 3µA 1-Cell/2-Cell Fuel Gauge with ModelGauge |  |  |  |  |  |  | Analog Devices |  |  |  |  |  | MAX17048G+T10 |  | TDFN-8 Maxim |  |  | None |  | https://www.snapeda.com/api/url_track_click_mouser/?unipart_id=329239&manufacturer=Analog Devices&part_name=MAX17048G+T10&search_term=None |  | https://www.snapeda.com/parts/MAX17048G+T10/Analog+Devices/view-part/?ref=snap
U5 | W25Q512JVEIQ | W25Q512JVEIQ | SON127P600X800X80-9N | Check availability |  |  | In Stock |  | https://www.snapeda.com/parts/W25Q512JVEIQ/Winbond+Electronics/view-part/?ref=eda |  |  | FLASH - NOR Memory IC 512Mb (64M x 8) SPI - Quad I/O 133 MHz 8-WSON (8x6) |  |  |  |  |  |  | Winbond Electronics |  |  |  |  |  | W25Q512JVEIQ |  | Package |  |  | None |  |  |  | https://www.snapeda.com/parts/W25Q512JVEIQ/Winbond+Electronics/view-part/?ref=snap

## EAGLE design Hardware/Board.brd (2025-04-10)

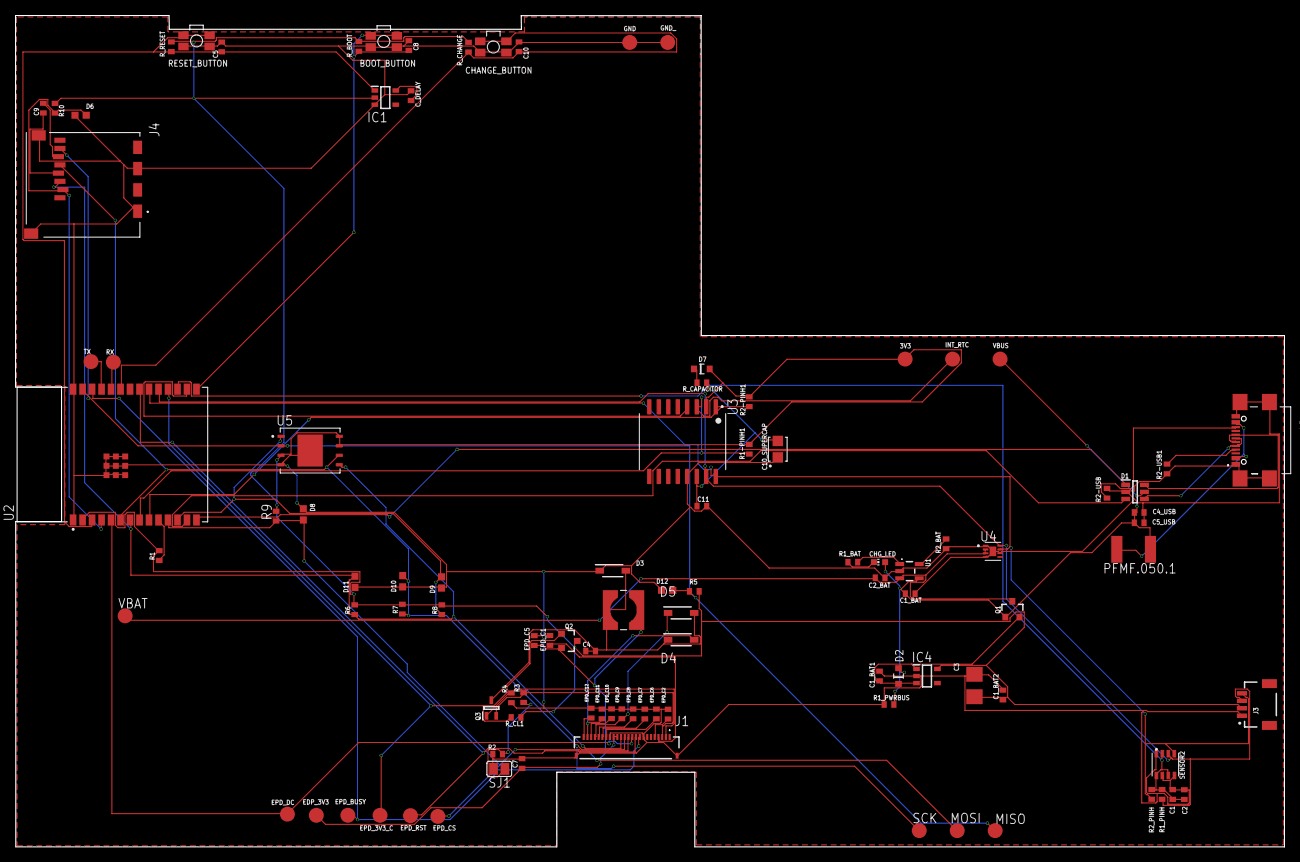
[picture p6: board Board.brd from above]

Board: 2 copper layers, 169.8 x 111.2 mm, 103 parts (0 on the bottom side), 56 nets.

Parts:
3V3: TPTP20R; TP20R
BOOT_BUTTON: BUTTON_CUSYOMV1; MYBUTTON
C1, C2: 100nF; ESP32_WROVER_EAGLE-LTSPICE_C0402
C1_BAT, C1_BAT1, C1_BAT2, C2_BAT, C5_USB: 4.7uF; EAGLE-LTSPICE_C0402
C3: 100uF TANT; RCL_CT3528
C4: 4.7uF/25V; EAGLE-LTSPICE_C0402
C4_USB, C8, C10, C11: 100nF; EAGLE-LTSPICE_C0402
C5: 1uF; EAGLE-LTSPICE_C0402
C7: 10uF; EAGLE-LTSPICE_C0402
C9: EAGLE-LTSPICE_C0402
C10_SUPERCAP: CPH3225A; CAPCP3225X100N
CHANGE_BUTTON: BUTTON_CUSYOMV1; MYBUTTON
CHG_LED: ADAFRUIT_CHIP-LED0603
C_DELAY: 100nF; EAGLE-LTSPICE_C0402
D1: USBLC6-2SC6Y; SOT95P280X145-6N
D2, D7: ESP32_WROVER_AVX---SD0805S020S1R0_AVX_SD0805S020S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; ESP32_WROVER_AVX---SD0805S020S1R0_AVX_SD0805S020S1R0_0
D3, D4, D5: MBR0530; SOD3716X135N
D6, D8, D9, D10, D11, D12: PGB1010603MR; DIOC1608X36N
EDP_3V3: TPTP20R; TP20R
EPD_3V3_C: TPTP20R; TP20R
EPD_BUSY: TPTP20R; TP20R
EPD_C1, EPD_C2, EPD_C6, EPD_C7, EPD_C8, EPD_C9, EPD_C10, EPD_C11, EPD_C12: 1uF/50V; EAGLE-LTSPICE_C0402
EPD_C5: 0.1uF/50V; EAGLE-LTSPICE_C0402
EPD_CS: TPTP20R; TP20R
EPD_DC: TPTP20R; TP20R
EPD_RST: TPTP20R; TP20R
GND: TPTP20R; TP20R
GND_: TPTP20R; TP20R
IC1: BD5229G-TR; SOT95P280X125-5N
IC4: XC6220A331MR-G; SOT95P280X120-5N
INT_RTC: TPTP20R; TP20R
J1: FH34SRJ-24S-0.5SH_99_; FH34SRJ24S05SH99
J2: SAMACSYS_PARTS_USB4110-GF-A; SAMACSYS_PARTS_USB4110GFA
J3: QWIIC_RIGHT_ANGLE; JST04_1MM_RA
J4: 112A-TAAR-R03_ATTEND; 112ATAARR03ATTEND
L1: 68uH; IND_4828-WE-TPC_WRE
MISO: TPTP20R; TP20R
MOSI: TPTP20R; TP20R
PFMF.050.1: ESP32C6_VARISTORCN1812; ESP32C6_VARISTOR_CT/CN1812
Q1, Q2: 20V/4.2A/52mΩ/1.4W; ESP32_WROVER_SPARKFUN-DISCRETESEMI_SOT23-3
Q3: SI1308EDL-T1-GE3; SOT65P210X110-3N
R1, R4: 10K; ESP32_WROVER_EAGLE-LTSPICE_R0402
R1-PINH1, R2-PINH1, R5, R6, R7, R8, R9, R10: 10k; ESP32_WROVER_EAGLE-LTSPICE_R0402
R1_BAT: 200; ESP32_WROVER_EAGLE-LTSPICE_R0402
R1_PINH, R2_PINH: ESP32_WROVER_EAGLE-LTSPICE_R0402
R1_PWRBUS: 100k; ESP32_WROVER_EAGLE-LTSPICE_R0402
R2: 2.2; ESP32_WROVER_EAGLE-LTSPICE_R0402
R2-USB, R2-USB1: 5k1; ESP32_WROVER_EAGLE-LTSPICE_R0402
R2_BAT: 2k; ESP32_WROVER_EAGLE-LTSPICE_R0402
R3: 0.47; ESP32_WROVER_EAGLE-LTSPICE_R0402
RESET_BUTTON: BUTTON_CUSYOMV1; MYBUTTON
RX: TPTP20R; TP20R
R_BOOT: 10k; ESP32_WROVER_EAGLE-LTSPICE_R0402
R_CAPACITOR: 15; ESP32_WROVER_EAGLE-LTSPICE_R0402
R_CHANGE: 10k; ESP32_WROVER_EAGLE-LTSPICE_R0402
R_CL1: 10K; ESP32_WROVER_EAGLE-LTSPICE_R0402
R_RESET: 10k; ESP32_WROVER_EAGLE-LTSPICE_R0402
SCK: TPTP20R; TP20R
SENSOR2: BME688; ESP32_WROVER_BME680_PSON80P300X300X100-8N
SJ1: SJ
TX: TPTP20R; TP20R
U1: ESP32_WROVER_SPARKFUN-IC-POWER_MCP73831; ESP32_WROVER_SPARKFUN-IC-POWER_SOT23-5
U2: ESP32-C6-WROOM-1-N8; XCVR_ESP32-C6-WROOM-1-N8
U3: DS3231SN#; SOIC127P1032X265-16N
U4: MAX17048G+T10; SON50P200X200X80-9N
U5: W25Q512JVEIQ; SON127P600X800X80-9N
VBAT: TPTP20R; TP20R
VBUS: TPTP20R; TP20R

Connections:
3V3: 3V3.TP, C1_BAT2.1, C3.+, D7.2, IC1.2, IC4.5, J3.2, Q2.3, R1.2, R1-PINH1.2, R2-PINH1.2, R5.2, R6.2, R7.2, R8.2, R9.2, R10.2, R_BOOT.2, R_CHANGE.2, R_CL1.2, R_RESET.2, U2.2, U3.2, U5.3, U5.7, U5.8
32KHZ: R2-PINH1.1, U2.9, U3.1
DN: D1.4, J2.A7, J2.B7
DP: D1.6, J2.A6, J2.B6
EPD_3V3: C7.1, EDP_3V3.TP, EPD_C5.1, J1.15, J1.16, L1.2, Q2.2
EPD_3V3_C: EPD_3V3_C.TP, Q2.1, R_CL1.1, U2.18
EPD_BUSY: EPD_BUSY.TP, J1.9, U2.26
EPD_CS: D8.2, EPD_CS.TP, J1.12, R9.1, U2.11
EPD_DC: EPD_DC.TP, J1.11, U2.5
EPD_RST: EPD_RST.TP, J1.10, U2.21
FLASH_CS: D9.2, R8.1, U2.12, U5.1
GDR: J1.2, Q3.1, R4.2
GND: BOOT_BUTTON.1, BOOT_BUTTON.2, C1.2, C1_BAT.2, C1_BAT1.2, C1_BAT2.2, C2.2, C2_BAT.2, C3.-, C4_USB.2, C5.2, C5_USB.2, C7.2, C8.2, C10.2, C10_SUPERCAP.1, C11.2, CHANGE_BUTTON.1, CHANGE_BUTTON.2, C_DELAY.2, D1.2, D3.1, D6.1, D8.1, D9.1, D10.1, D11.1, D12.1, EPD_C1.2, EPD_C2.2, EPD_C5.2, EPD_C6.2, EPD_C7.2, EPD_C8.2, EPD_C9.2, EPD_C10.2, EPD_C11.2, EPD_C12.2, GND.TP, GND_.TP, IC1.3, IC4.2, J1.8, J1.17, J1.MP1, J1.MP2, J2.A1, J2.A12, J2.B1, J2.B12, J2.MP1, J2.MP2, J2.MP3, J2.MP4, J3.1, J4.G1, J4.G2, J4.G3, J4.G4, R1_PWRBUS.1, R2.1, R2-USB.2, R2-USB1.1, R2_BAT.1, R4.1, RESET_BUTTON.1, RESET_BUTTON.2, SENSOR2.1, SENSOR2.5, SENSOR2.7, SJ1.1, U1.2, U2.1, U2.28, U2.29_1, U2.29_2, U2.29_3, U2.29_4, U2.29_5, U2.29_6, U2.29_7, U2.29_8, U2.29_9, U3.13, U4.1, U4.4, U4.6, U4.9, U5.4, U5.9
GPIO8: R1.1, U2.10
I2C_PW: C1.1, C2.1, R1_PINH.2, R2_PINH.2, SENSOR2.2, SENSOR2.6, SENSOR2.8, U2.17
INT_RTC: INT_RTC.TP, R1-PINH1.1, U2.8, U3.3
IO/BOOT: BOOT_BUTTON.3, BOOT_BUTTON.4, C8.1, R_BOOT.1, U2.15
IO/CHANGE: C10.1, CHANGE_BUTTON.3, CHANGE_BUTTON.4, R_CHANGE.1, U2.23
MISO: D12.2, J4.P7, MISO.TP, R5.1, U2.27, U5.2
MOSI: D11.2, J1.14, J4.P3, MOSI.TP, R6.1, U2.7, U5.5
unnamed: C9.1, J4.P4
unnamed: J2.B5, R2-USB.1
unnamed: J2.A5, R2-USB1.2
unnamed: C1_BAT1.1, D2.1, IC4.1, IC4.3, Q1.2
unnamed: R1_BAT.2, U1.1
unnamed: CHG_LED.C, R1_BAT.1
unnamed: R2_BAT.2, U1.5
unnamed: EPD_C1.1, J1.4
unnamed: EPD_C2.1, J1.5
unnamed: EPD_C6.1, J1.18
unnamed: EPD_C7.1, J1.19
unnamed: EPD_C8.1, J1.20
unnamed: EPD_C10.1, J1.22
unnamed: EPD_C12.1, J1.24
unnamed: C_DELAY.1, IC1.5
unnamed: D7.1, R_CAPACITOR.1
unnamed: C9.2, J4.P6
PREVGH: D5.1, EPD_C9.1, J1.21
PREVGL: D4.2, EPD_C11.1, J1.23
RESE: J1.3, Q3.2, R3.2
RESE': R2.2, R3.1, SJ1.2
RESET: C5.1, IC1.1, RESET_BUTTON.3, RESET_BUTTON.4, R_RESET.1, U2.3
RTC_RST: U2.16, U3.4
RX: RX.TP, U2.24
SCK: D10.2, J1.13, J4.P5, R7.1, SCK.TP, U2.6, U5.6
SCL: J3.4, R2_PINH.1, SENSOR2.4, U2.20, U3.16, U4.7
SDA: J3.3, R1_PINH.1, SENSOR2.3, U2.19, U3.15, U4.8
SRC: C4.1, C4.2, D3.2, D4.1, D5.2, L1.1, Q3.3
SS_SD: D6.2, J4.P2, R10.1, U2.4
TX: TX.TP, U2.25
USB_D+: D1.1, U2.14
USB_D-: D1.3, U2.13
VBAT: C2_BAT.1, Q1.3, U1.3, U4.2, U4.3, VBAT.TP
VBUS: C1_BAT.1, C4_USB.1, C5_USB.1, CHG_LED.A, D1.5, D2.2, PFMF.050.1.2, Q1.1, R1_PWRBUS.2, U1.4, VBUS.TP
VRTC: C10_SUPERCAP.2, C11.1, R_CAPACITOR.2, U3.14
VUSB: J2.A4, J2.A9, J2.B4, J2.B9, PFMF.050.1.1

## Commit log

2025-04-06 finished board
    [Board.brd]
2025-04-06 final changes on board
    [Board.brd]
2025-04-10 modified schematic (added names of the components)
    [Schematic.sch]
2025-04-10 fixed names on board so its readable
    [Board.brd]
2025-04-11 3d board

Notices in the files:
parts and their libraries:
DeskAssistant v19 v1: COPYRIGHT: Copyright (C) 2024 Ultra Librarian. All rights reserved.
